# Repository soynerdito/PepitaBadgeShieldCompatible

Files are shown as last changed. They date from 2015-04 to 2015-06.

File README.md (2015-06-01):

# PepitaBadgeShieldCompatible
BSides Badge (codename Pepita). Arduino shield compatible.

To program board use an external USBAS at 5V. Connect 5V input voltage via the pin that says 3.3V to send 5V straight to the  atmega chip. If input voltage goes to the input pin it will go through the 3.3V regulator and in my first test it didn't allowed me to program the chip.

#Configure Arduino IDE 1.6.4
Step 1:
File->Preferences
 Paste in "Additional Boards Manager URLS:" https://github.com/soynerdito/PepitaBadgeShieldCompatible/raw/master/Arduino/IDE_Board_Manager/package_bsidespr_index.json
Click OK

Step 2:
Tools->Boards->Boards Manager
	Select BSides Badge from list and click Install

Step 3: Activate the board
Tools->Boads
	Select BSides Badge 2015 from the available boards
	
Step 4: Set the programmer
Tools->Programmer
	Select USBasp

# Flashing firmware
avrdude -c usbasp -b 19200 -p atmega328p -P /dev/ttyACM0 -U flash:w:mega32p_16mhz_program_on_reset.hex

#Fuses
avrdude -c usbasp -p atmega328p -b19200 -P /dev/ttyACM0 -U lfuse:w:0xf7:m -U hfuse:w:0xdA:m -U efuse:w:0x03:m

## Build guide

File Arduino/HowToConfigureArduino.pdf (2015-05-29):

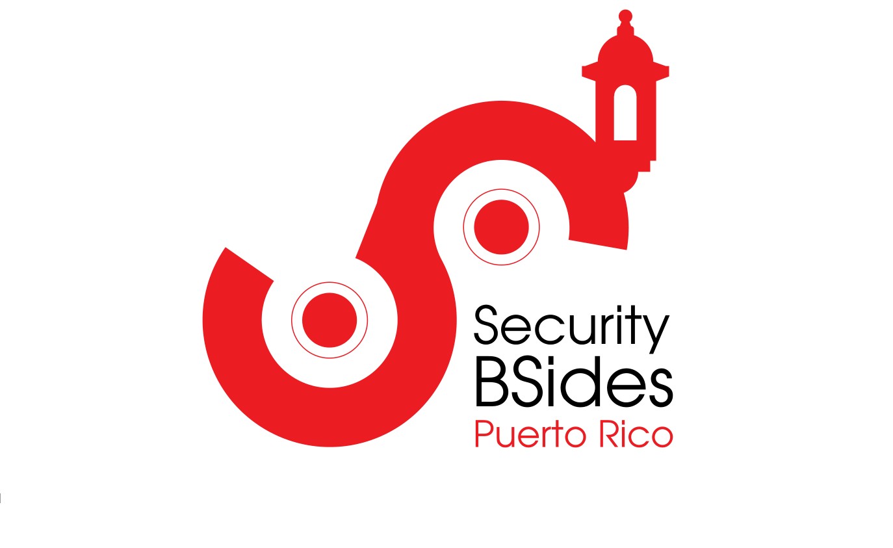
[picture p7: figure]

# How to Configure Arduino 1.6.4 for Bsides PR 2015 Badge

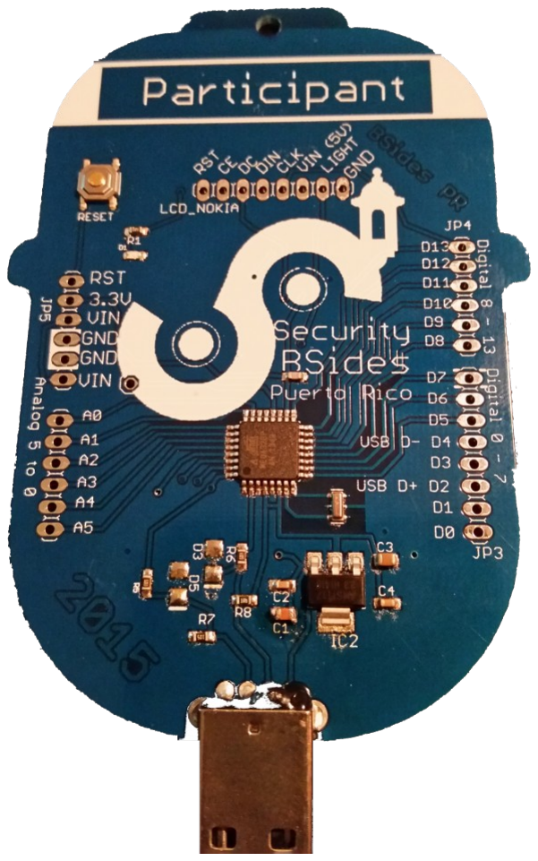
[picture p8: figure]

1

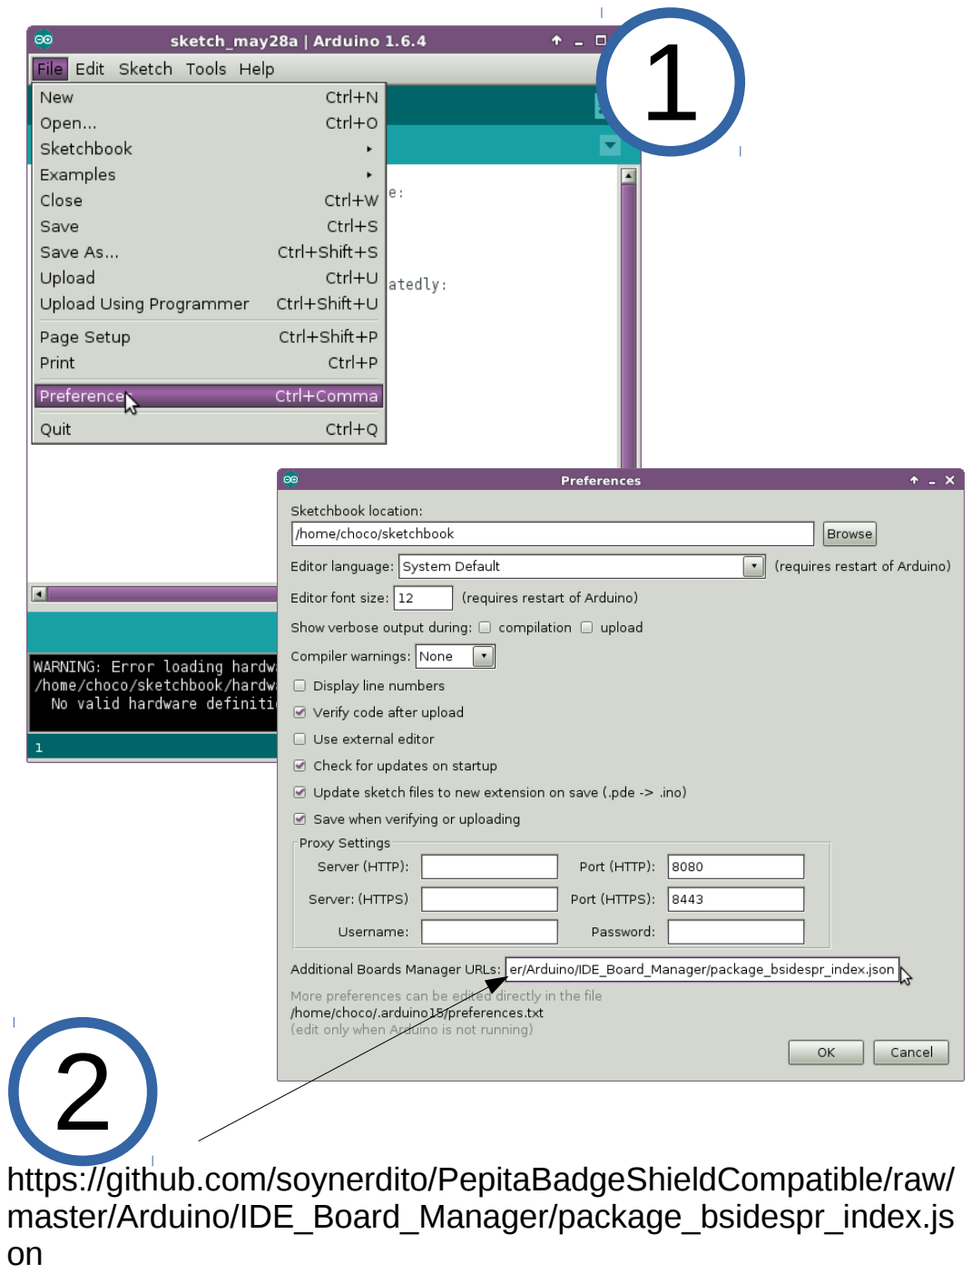
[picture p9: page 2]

https://github.com/soynerdito/PepitaBadgeShieldCompatible/raw/master/Arduino/IDE_Board_Manager/package_bsidespr_index.js on

2

3

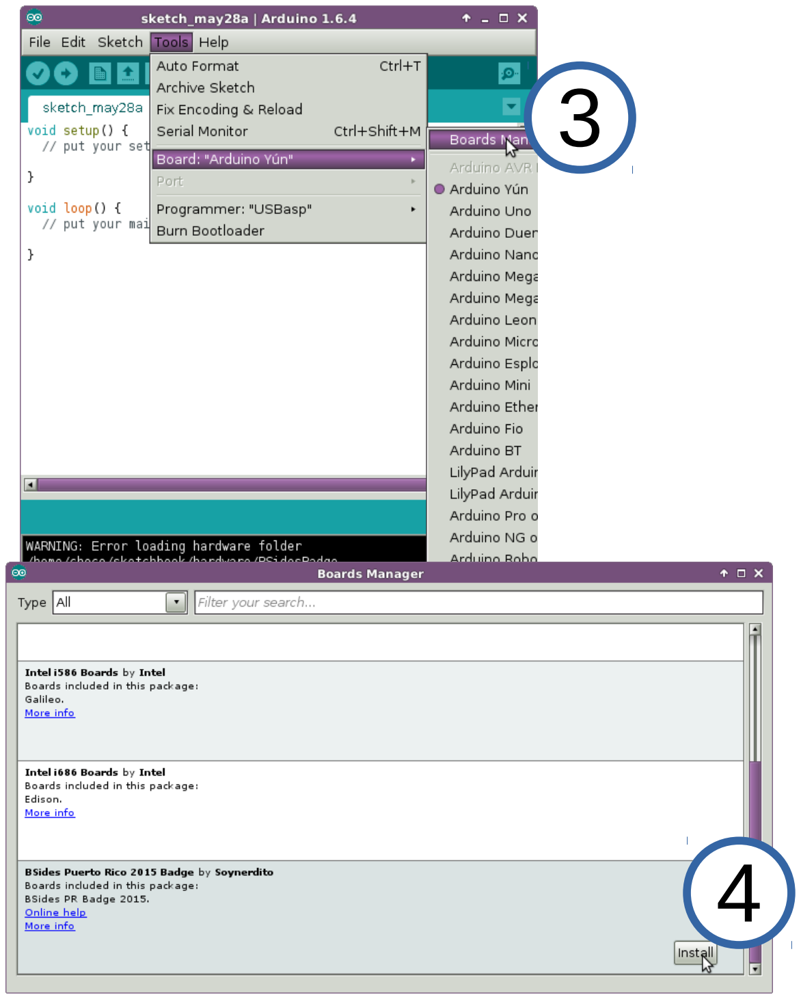
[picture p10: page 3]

4

5

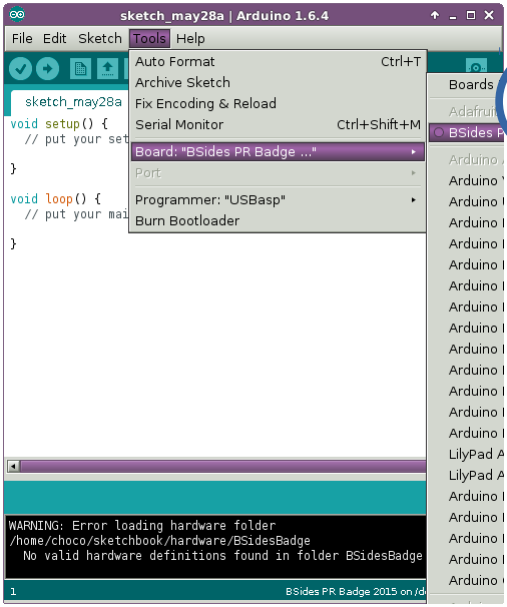
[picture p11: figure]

Your IDE is ready to compile and download projects to your badge.
Linux/MAC no drivers needed

Linux
create a file /etc/udev/rules.d/Usbasp.rules with this content SUBSYSTEMS=="usb", ATTRS{idVendor}=="16c0", ATTRS{idProduct}=="05dc", GROUP="users", MODE="0666"

Windows
Driver: http://www.fischl.de/usbasp/

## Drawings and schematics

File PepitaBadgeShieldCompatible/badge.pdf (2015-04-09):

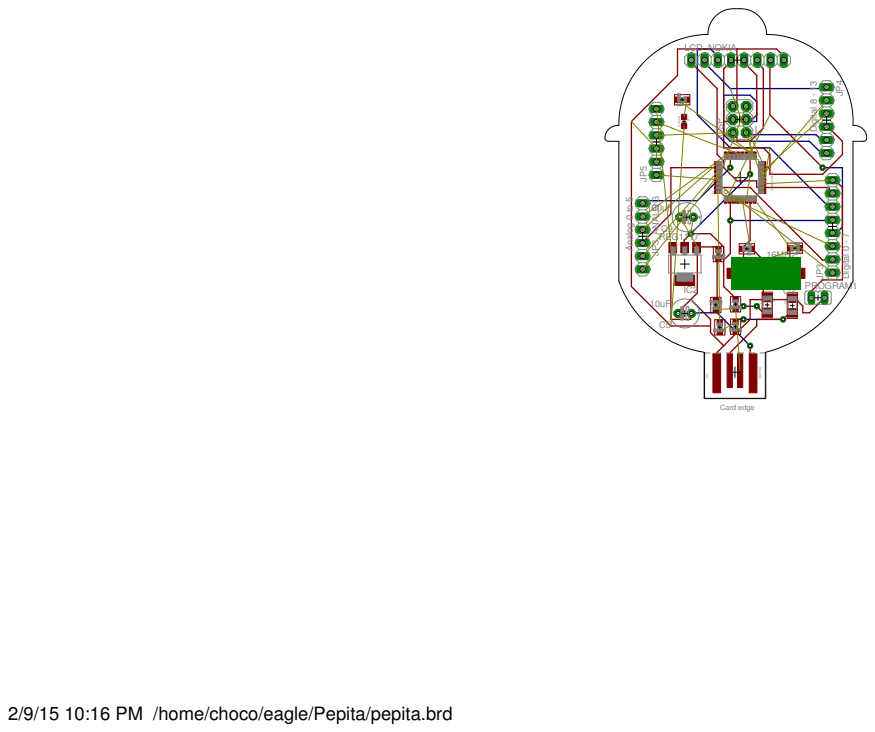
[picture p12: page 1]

2/9/15 10:16 PM /home/choco/eagle/Pepita/pepita.brd

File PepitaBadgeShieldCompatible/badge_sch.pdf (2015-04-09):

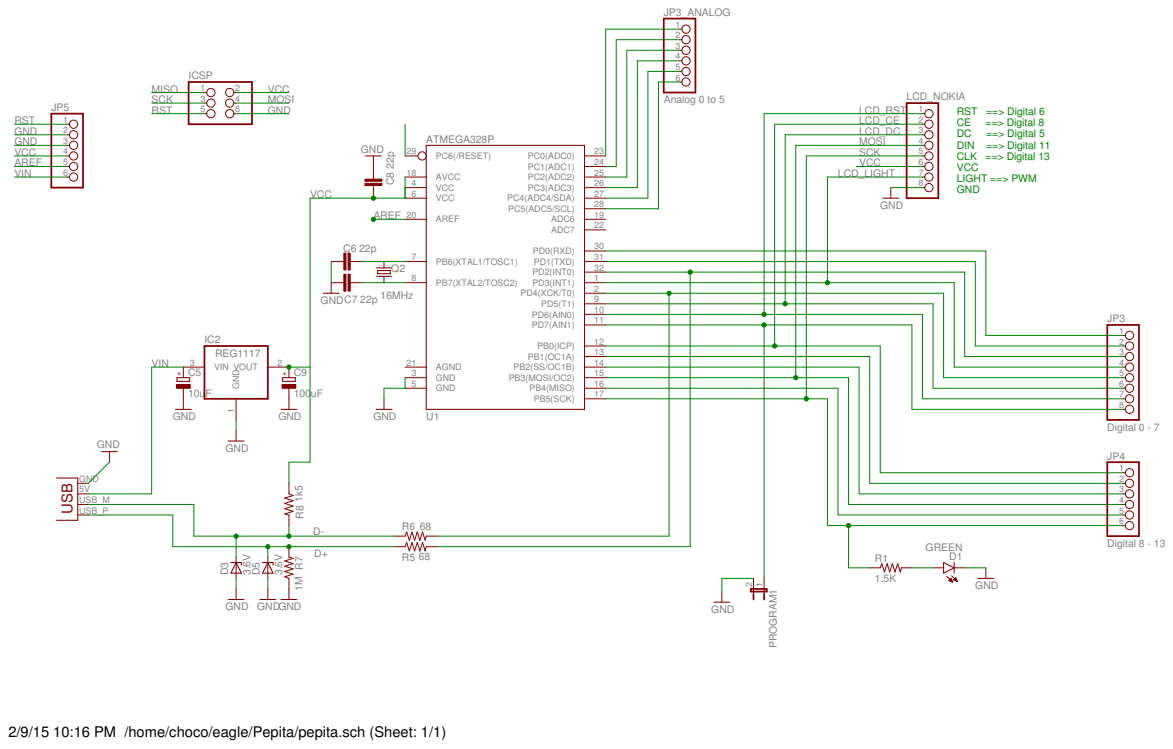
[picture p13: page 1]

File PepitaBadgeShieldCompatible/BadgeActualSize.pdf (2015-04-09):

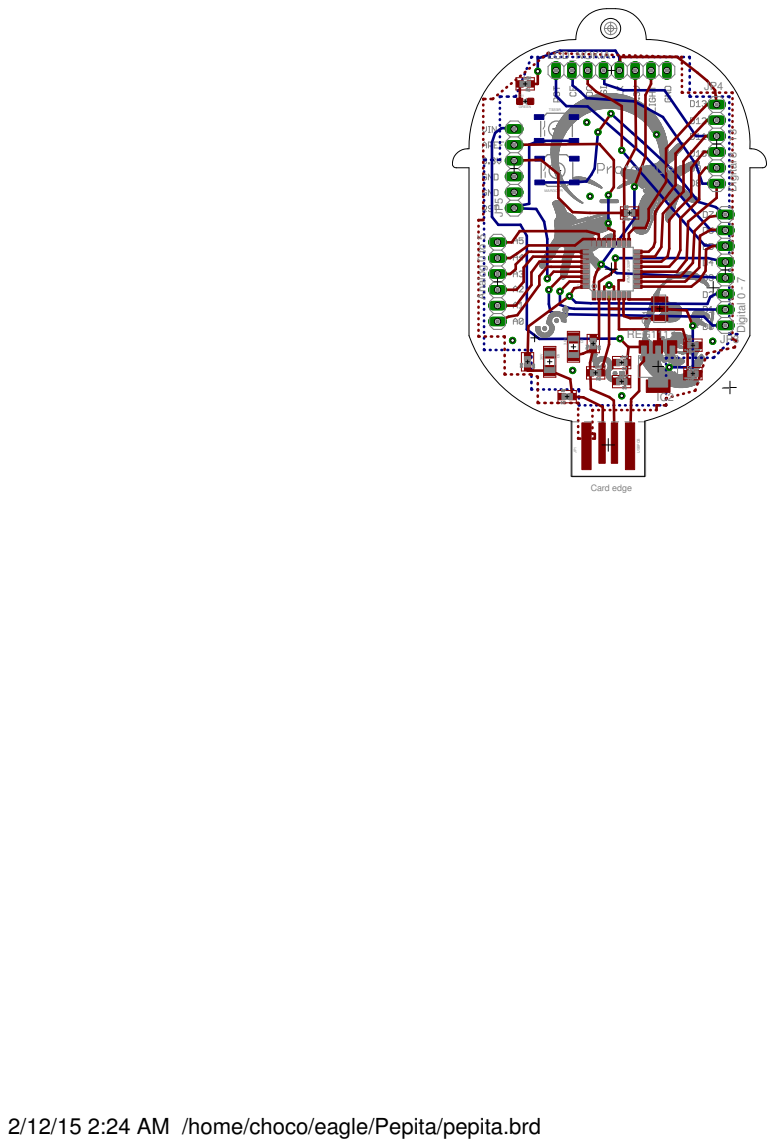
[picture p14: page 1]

2/12/15 2:24 AM /home/choco/eagle/Pepita/pepita.brd

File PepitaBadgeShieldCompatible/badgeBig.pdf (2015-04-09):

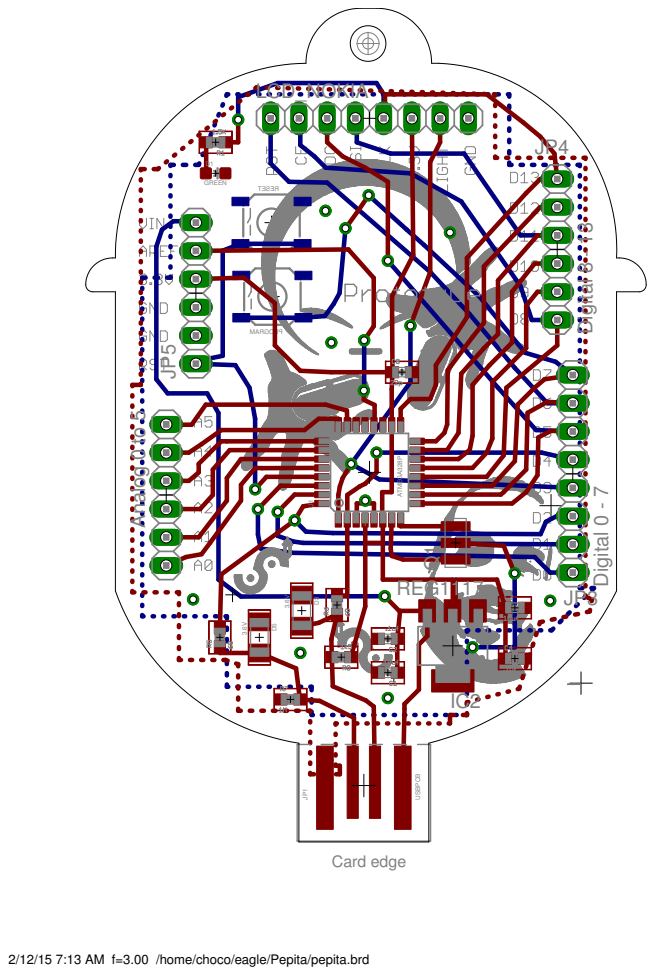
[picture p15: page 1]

2/12/15 7:13 AM f=3.00 /home/choco/eagle/Pepita/pepita.brd

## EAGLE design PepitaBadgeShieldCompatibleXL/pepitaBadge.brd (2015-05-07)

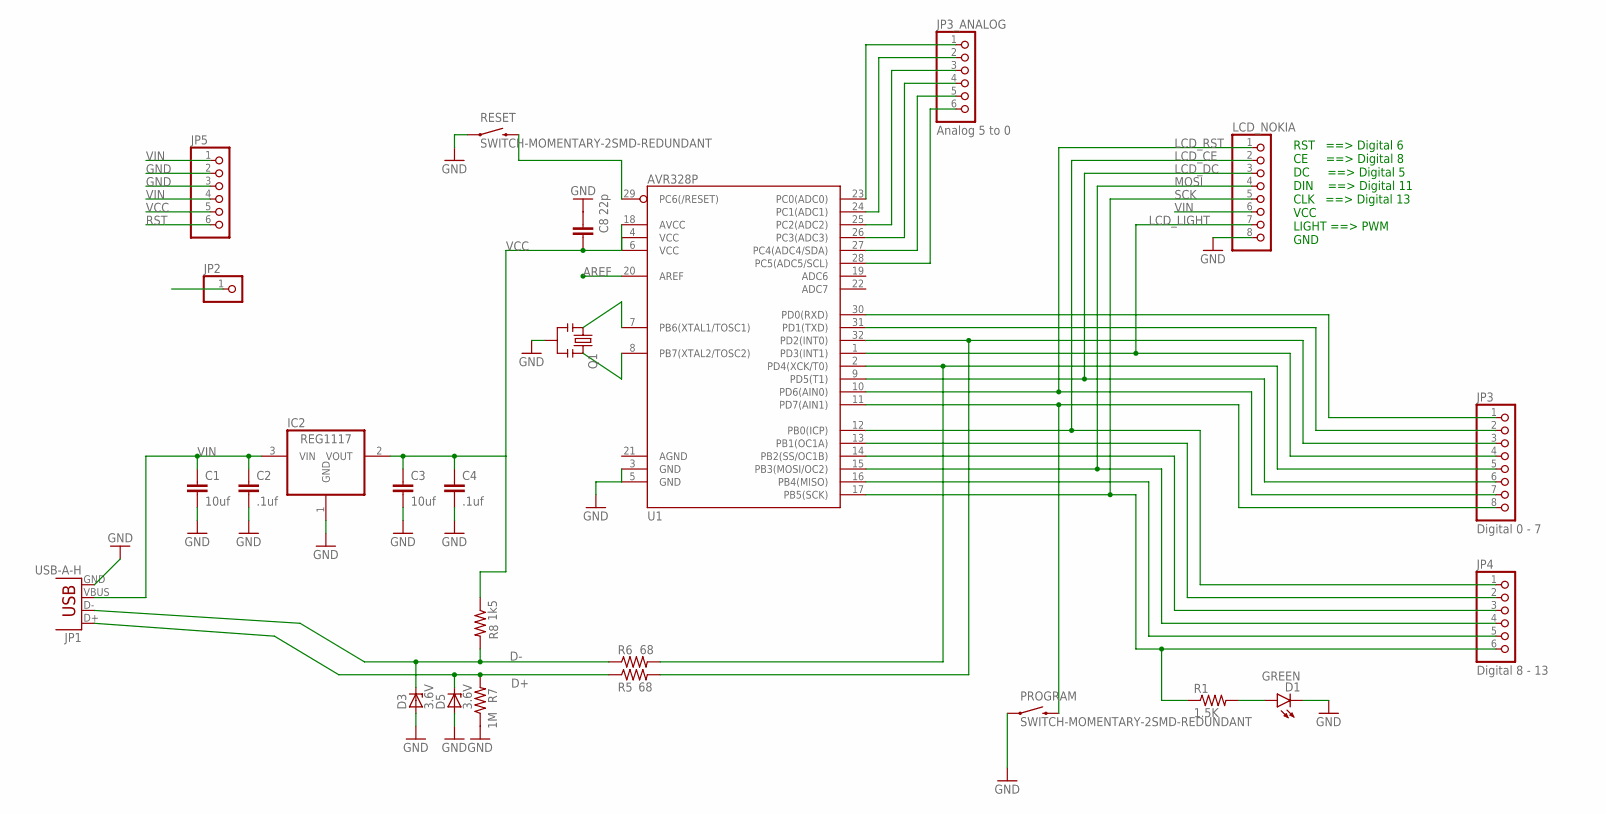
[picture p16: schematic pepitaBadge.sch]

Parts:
C1, C3: 10uf; 0805
C2, C4: .1uf; 0603-CAP
C8: 22p; 0603-CAP
D1: GREEN; LED-0603
D3, D5: 3.6V; 1206
IC2: REG1117; SOT223
JP1: USB-A-H
JP2: PINHD-1X1; 1X01
JP3: Digital 0 - 7; 1X08
JP3_ANALOG: Analog 5 to 0; 1X06
JP4: Digital 8 - 13; 1X06
JP5: PINHD-1X6; 1X06
LCD_NOKIA: PINHD-1X8; 1X08
PROGRAM: SWITCH-MOMENTARY-2SMD-REDUNDANT; TACTILE-SWITCH-SMD
Q1: RESONATOR16MHZ; RESONATOR-SMD
R1: 1.5K; 0603-RES
R5, R6: 68; 0603-RES
R7: 1M; 0603-RES
R8: 1k5; 0603-RES
RESET: SWITCH-MOMENTARY-2SMD-REDUNDANT; TACTILE-SWITCH-SMD
U1: AVR328P; TQFP32-08

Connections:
A5: JP3_ANALOG.6, U1.28 (PC5(ADC5/SCL))
AREF: JP2.1, U1.20 (AREF)
D+: D5.2 (C), JP1.D+, R5.1, R7.2
D-: D3.2 (C), JP1.D-, R6.1, R8.2
GND: C1.2, C2.2, C3.2, C4.2, C8.2, D1.C, D3.1 (A), D5.1 (A), IC2.1 (GND), JP1.GND, JP5.2, JP5.3, LCD_NOKIA.8, PROGRAM.1, PROGRAM.2 (1), Q1.2, R7.1, RESET.1, RESET.2 (1), U1.3 (GND), U1.5 (GND)
LCD_CE: JP4.1, LCD_NOKIA.2, U1.12 (PB0(ICP))
LCD_DC: JP3.6, LCD_NOKIA.3, U1.9 (PD5(T1))
LCD_LIGHT: JP3.4, LCD_NOKIA.7, U1.1 (PD3(INT1))
LCD_RST: JP3.7, LCD_NOKIA.1, U1.10 (PD6(AIN0))
MISO: JP4.5, U1.16 (PB4(MISO))
MOSI: JP4.4, LCD_NOKIA.4, U1.15 (PB3(MOSI/OC2))
unnamed: D1.A, R1.2
unnamed: JP3_ANALOG.5, U1.27 (PC4(ADC4/SDA))
unnamed: JP3_ANALOG.4, U1.26 (PC3(ADC3))
unnamed: JP3_ANALOG.3, U1.25 (PC2(ADC2))
unnamed: JP3.5, R6.2, U1.2 (PD4(XCK/T0))
unnamed: JP3_ANALOG.2, U1.24 (PC1(ADC1))
unnamed: Q1.1, U1.7 (PB6(XTAL1/TOSC1))
unnamed: JP3_ANALOG.1, U1.23 (PC0(ADC0))
unnamed: Q1.3, U1.8 (PB7(XTAL2/TOSC2))
unnamed: JP4.2, U1.13 (PB1(OC1A))
unnamed: JP4.3, U1.14 (PB2(SS/OC1B))
unnamed: JP3.3, R5.2, U1.32 (PD2(INT0))
PD7: JP3.8, PROGRAM.3 (2), PROGRAM.4 (2), U1.11 (PD7(AIN1))
RST: JP5.6, RESET.3 (2), RESET.4 (2), U1.29 (PC6(/RESET))
RXD: JP3.1, U1.30 (PD0(RXD))
SCK: JP4.6, LCD_NOKIA.5, R1.1, U1.17 (PB5(SCK))
TXD: JP3.2, U1.31 (PD1(TXD))
VCC: C3.1, C4.1, C8.1, IC2.2 (VOUT), JP5.5, R8.1, U1.4 (VCC), U1.6 (VCC), U1.18 (AVCC)
VIN: C1.1, C2.1, IC2.3 (VIN), JP1.VBUS, JP5.1, JP5.4, LCD_NOKIA.6

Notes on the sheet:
RST ==> Digital 6 CE ==> Digital 8 DC ==> Digital 5 DIN ==> Digital 11 CLK ==> Digital 13 VCC LIGHT ==> PWM GND

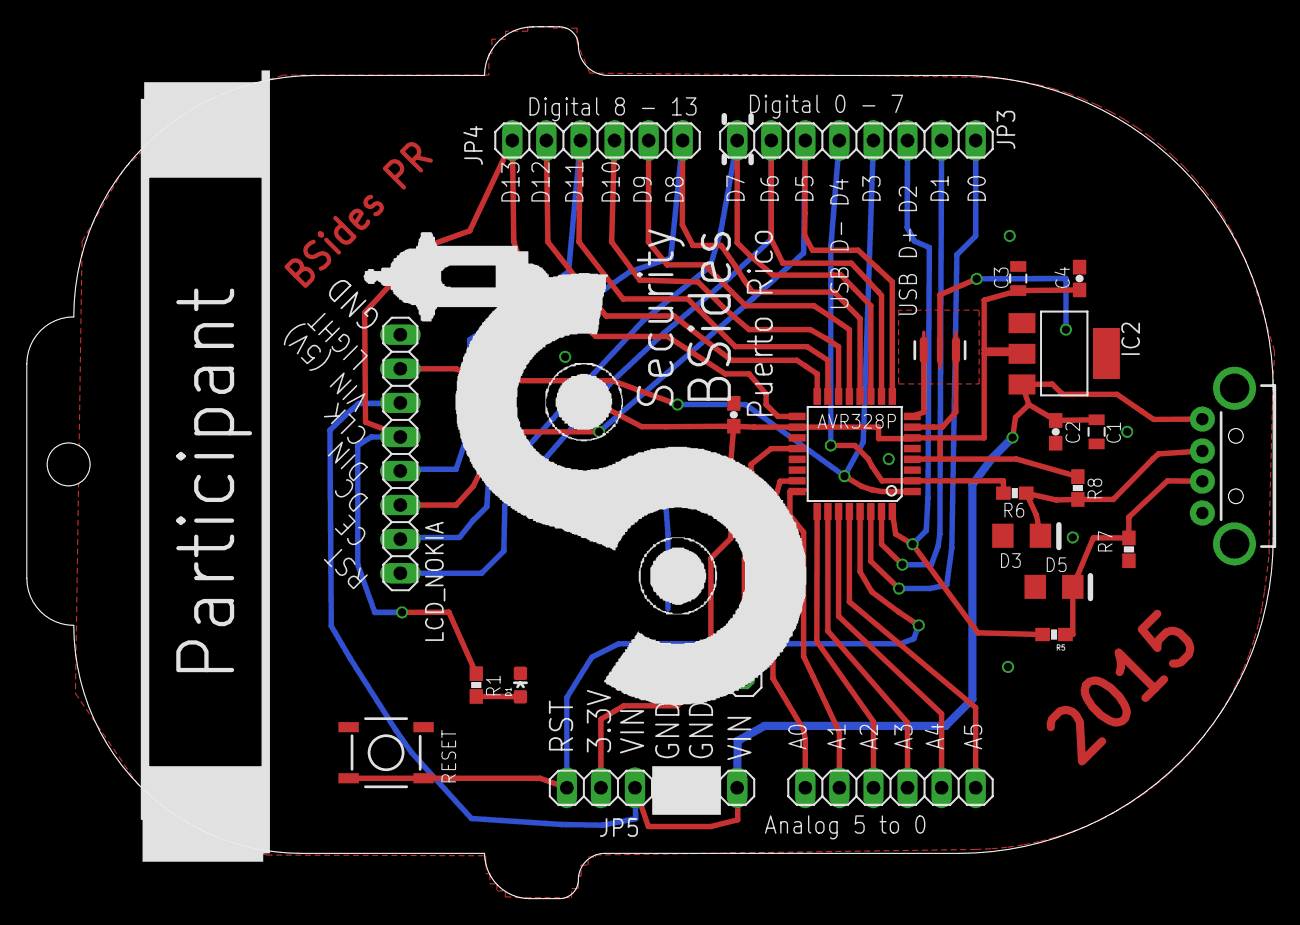
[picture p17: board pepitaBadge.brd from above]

Board: 2 copper layers, 92.9 x 65.0 mm, 27 parts (1 on the bottom side), 30 nets.

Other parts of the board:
U$2: OBSIDISLOGO_BOTTOM
U$5: BSIDES_LOGO_NTB_PIC_ONLY

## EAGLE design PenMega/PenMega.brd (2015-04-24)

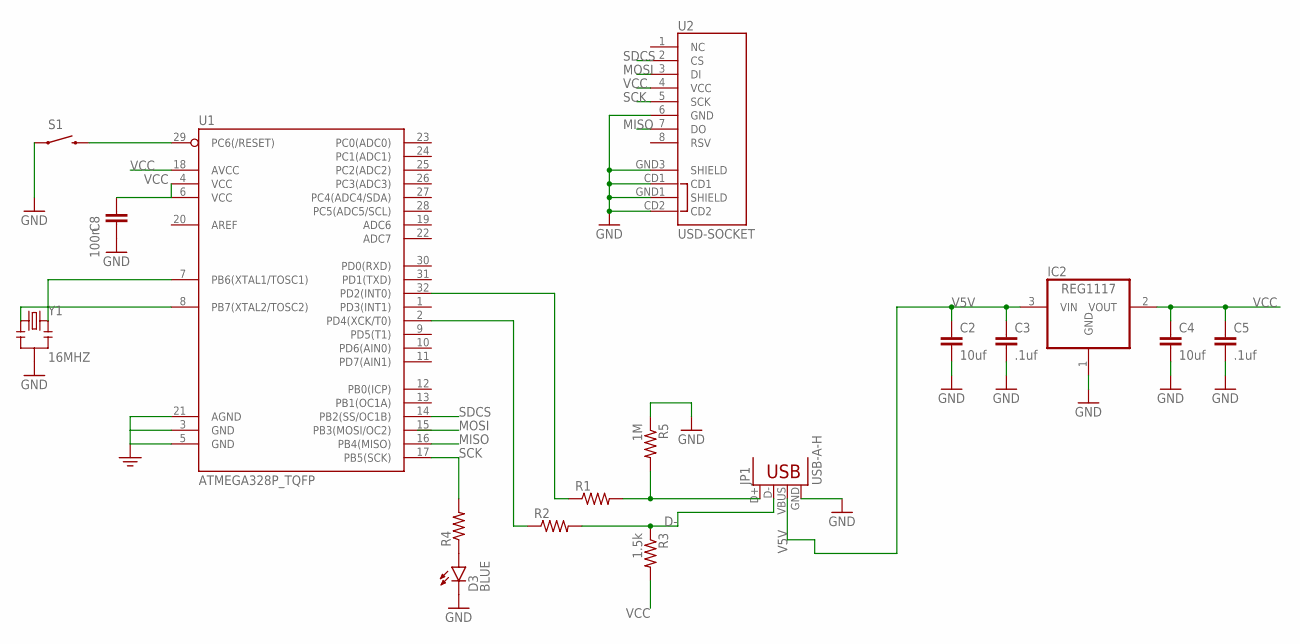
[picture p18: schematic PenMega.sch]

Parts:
C2, C4: 10uf; 0805
C3, C5: .1uf; 0603-CAP
C8: 100n; 0603-CAP
D3: BLUE; LED-0603
IC2: REG1117; SOT223
JP1: USB-A-H
R1, R2, R4: RESISTOR0603-RES; 0603-RES
R3: 1.5k; 0603-RES
R5: 1M; 0603-RES
S1: SWITCH-MOMENTARY-2SMD; TACTILE-SWITCH-SMD
U1: ATMEGA328P_TQFP; TQFP32-08
U2: USD-SOCKET; MICROSD_1:1
Y1: 16MHZ; RESONATOR-SMD

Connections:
D-: JP1.D-, R2.2, R3.1
GND: C2.2, C3.2, C4.2, C5.2, C8.2, D3.C, IC2.1 (GND), JP1.GND, R5.1, S1.1, U1.3 (GND), U1.5 (GND), U1.21 (AGND), U2.6 (GND), U2.CD1, U2.CD2, U2.GND1 (SHIELD), U2.GND3 (SHIELD), Y1.2
MISO: U1.16 (PB4(MISO)), U2.7 (DO)
MOSI: U2.3 (DI)
unnamed: U1.8 (PB7(XTAL2/TOSC2)), Y1.1
unnamed: U1.7 (PB6(XTAL1/TOSC1)), Y1.3
unnamed: JP1.D+, R1.2, R5.2
unnamed: R2.1, U1.2 (PD4(XCK/T0))
unnamed: R1.1, U1.32 (PD2(INT0))
unnamed: S1.3 (2), U1.29 (PC6(/RESET))
unnamed: D3.A, R4.1
SCK: R4.2, U1.17 (PB5(SCK)), U2.5 (SCK)
SDCS: U1.14 (PB2(SS/OC1B)), U2.2 (CS)
V5V: C2.1, C3.1, IC2.3 (VIN), JP1.VBUS
VCC: C4.1, C5.1, C8.1, IC2.2 (VOUT), R3.2, U1.4 (VCC), U1.6 (VCC), U1.18 (AVCC), U2.4 (VCC)

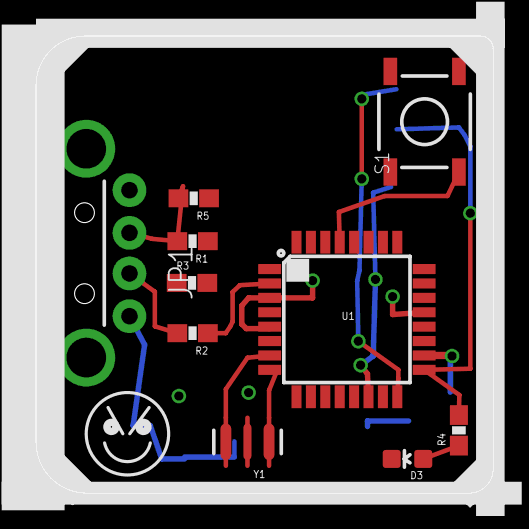
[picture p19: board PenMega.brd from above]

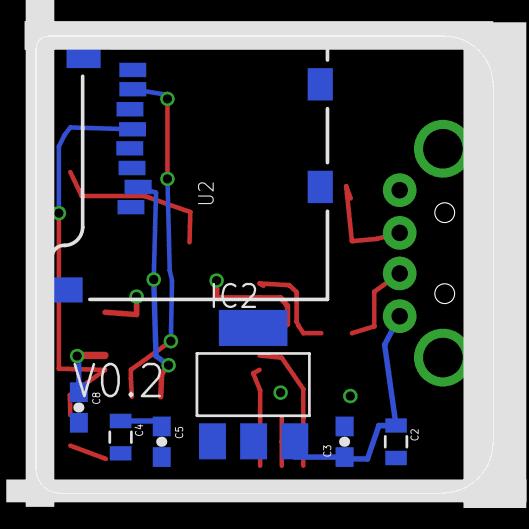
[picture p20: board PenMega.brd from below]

Board: 2 copper layers, 25.4 x 25.4 mm, 17 parts (7 on the bottom side), 14 nets.

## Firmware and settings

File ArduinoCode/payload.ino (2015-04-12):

#include "UsbKeyboard.h"

#define BUTTON_PIN 7

// If the timer isr is corrected
// to not take so long change this to 0.
#define BYPASS_TIMER_ISR 1

void doPayload();


void setup() {
  pinMode(BUTTON_PIN, INPUT);
  digitalWrite(BUTTON_PIN, HIGH);
  
#if BYPASS_TIMER_ISR
  // disable timer 0 overflow interrupt (used for millis)
  TIMSK0&=!(1<<TOIE0); // ++
#endif

}


#if BYPASS_TIMER_ISR
void delayMs(unsigned int ms) {
   /*
  */ 
  for (int i = 0; i < ms; i++) {
    delayMicroseconds(1000);
  }
}
#endif


void sendKeys( int keys[] )
{
  int i=0;
  while(keys[i] != 0 )
  {
    UsbKeyboard.sendKeyStroke( keys[i] );
    i++;
  }
}
int skipCount=0;
void loop() {
  
  UsbKeyboard.update();

  digitalWrite(13, !digitalRead(13));

  if( skipCount > 100 ){
    doPayload();
    skipCount = 0;
  }
  skipCount++;
     
  waitSome(120);
}

void waitSome( unsigned ms ){
  #if BYPASS_TIMER_ISR  // check if timer isr fixed.
      delayMs(ms);
  #else
      delay(ms);
  #endif
}
//Example Mod Keys
//UsbKeyboard.sendKeyStroke(KEY_R,    MOD_GUI_LEFT);
//UsbKeyboard.sendKeyStroke(KEY_F3,    MOD_ALT_LEFT);
/*
MOD_CONTROL_LEFT
MOD_SHIFT_LEFT
MOD_ALT_LEFT
MOD_GUI_LEFT
MOD_CONTROL_RIGHT
MOD_SHIFT_RIGHT
MOD_ALT_RIGHT
MOD_GUI_RIGHT
*/


void onWrite(unsigned char*, unsigned char )
{

}
void doPayload(){
	UsbKeyboard.sendKeyStroke( KEY_P );
	UsbKeyboard.sendKeyStroke( KEY_L );
	UsbKeyboard.sendKeyStroke( KEY_U );
	UsbKeyboard.sendKeyStroke( KEY_M );
	UsbKeyboard.sendKeyStroke( KEY_A );
	UsbKeyboard.sendKeyStroke( KEY_ENTER );
	UsbKeyboard.sendKeyStroke( KEY_ENTER );
	UsbKeyboard.sendKeyStroke( KEY_ENTER );
	UsbKeyboard.sendKeyStroke( KEY_E );
	UsbKeyboard.sendKeyStroke( KEY_S );
	UsbKeyboard.sendKeyStroke( KEY_T );
	UsbKeyboard.sendKeyStroke( KEY_E );
	UsbKeyboard.sendKeyStroke( KEY_SPACE );
	UsbKeyboard.sendKeyStroke( KEY_F );
	UsbKeyboard.sendKeyStroke( KEY_U );
	UsbKeyboard.sendKeyStroke( KEY_E );
	UsbKeyboard.sendKeyStroke( KEY_SPACE );
	UsbKeyboard.sendKeyStroke( KEY_M );
	UsbKeyboard.sendKeyStroke( KEY_I );
	UsbKeyboard.sendKeyStroke( KEY_SPACE );
	UsbKeyboard.sendKeyStroke( KEY_P );
	UsbKeyboard.sendKeyStroke( KEY_A );
	UsbKeyboard.sendKeyStroke( KEY_Y );
	UsbKeyboard.sendKeyStroke( KEY_L );
	UsbKeyboard.sendKeyStroke( KEY_O );
	UsbKeyboard.sendKeyStroke( KEY_A );
	UsbKeyboard.sendKeyStroke( KEY_D );
	UsbKeyboard.sendKeyStroke( KEY_ENTER );
	UsbKeyboard.sendKeyStroke( KEY_ENTER );
	UsbKeyboard.sendKeyStroke( KEY_O );
	UsbKeyboard.sendKeyStroke( KEY_SPACE );
	UsbKeyboard.sendKeyStroke( KEY_SPACE );
	UsbKeyboard.sendKeyStroke( KEY_SPACE );
	UsbKeyboard.sendKeyStroke( KEY_SPACE );
	UsbKeyboard.sendKeyStroke( KEY_SPACE );
	UsbKeyboard.sendKeyStroke( KEY_SPACE );
	UsbKeyboard.sendKeyStroke( KEY_SPACE );
	UsbKeyboard.sendKeyStroke( KEY_SPACE );
	UsbKeyboard.sendKeyStroke( KEY_SPACE );
	UsbKeyboard.sendKeyStroke( KEY_SPACE );
	UsbKeyboard.sendKeyStroke( KEY_TILDE );
	UsbKeyboard.sendKeyStroke( KEY_O );
	UsbKeyboard.sendKeyStroke( KEY_SPACE );
	UsbKeyboard.sendKeyStroke( KEY_SPACE );
	UsbKeyboard.sendKeyStroke( KEY_SPACE );
	UsbKeyboard.sendKeyStroke( KEY_SPACE );
	UsbKeyboard.sendKeyStroke( KEY_O );
	UsbKeyboard.sendKeyStroke( KEY_O );
	UsbKeyboard.sendKeyStroke( KEY_SPACE );
	UsbKeyboard.sendKeyStroke( KEY_SPACE );
	UsbKeyboard.sendKeyStroke( KEY_SPACE );
	UsbKeyboard.sendKeyStroke( KEY_SPACE );
	UsbKeyboard.sendKeyStroke( KEY_SPACE );
	UsbKeyboard.sendKeyStroke( KEY_PERIOD );
	UsbKeyboard.sendKeyStroke( KEY_O );
	UsbKeyboard.sendKeyStroke( KEY_O );
	UsbKeyboard.sendKeyStroke( KEY_O );
	UsbKeyboard.sendKeyStroke( KEY_O );
	UsbKeyboard.sendKeyStroke( KEY_O );
	UsbKeyboard.sendKeyStroke( KEY_PERIOD );
	UsbKeyboard.sendKeyStroke( KEY_SPACE );
	UsbKeyboard.sendKeyStroke( KEY_SPACE );
	UsbKeyboard.sendKeyStroke( KEY_SPACE );
	UsbKeyboard.sendKeyStroke( KEY_SPACE );
	UsbKeyboard.sendKeyStroke( KEY_SPACE );
	UsbKeyboard.sendKeyStroke( KEY_SPACE );
	UsbKeyboard.sendKeyStroke( KEY_SPACE );
	UsbKeyboard.sendKeyStroke( KEY_SPACE );
	UsbKeyboard.sendKeyStroke( KEY_SPACE );
	UsbKeyboard.sendKeyStroke( KEY_PERIOD );
	UsbKeyboard.sendKeyStroke( KEY_O );
	UsbKeyboard.sendKeyStroke( KEY_O );
	UsbKeyboard.sendKeyStroke( KEY_O );
	UsbKeyboard.sendKeyStroke( KEY_O );
	UsbKeyboard.sendKeyStroke( KEY_O );
	UsbKeyboard.sendKeyStroke( KEY_PERIOD );
	UsbKeyboard.sendKeyStroke( KEY_SPACE );
	UsbKeyboard.sendKeyStroke( KEY_SPACE );
	UsbKeyboard.sendKeyStroke( KEY_SPACE );
	UsbKeyboard.sendKeyStroke( KEY_O );
	UsbKeyboard.sendKeyStroke( KEY_SPACE );
	UsbKeyboard.sendKeyStroke( KEY_SPACE );
	UsbKeyboard.sendKeyStroke( KEY_SPACE );
	UsbKeyboard.sendKeyStroke( KEY_SPACE );
	UsbKeyboard.sendKeyStroke( KEY_SPACE );
	UsbKeyboard.sendKeyStroke( KEY_SPACE );
	UsbKeyboard.sendKeyStroke( KEY_SPACE );
	UsbKeyboard.sendKeyStroke( KEY_O );
	UsbKeyboard.sendKeyStroke( KEY_SPACE );
	UsbKeyboard.sendKeyStroke( KEY_O );
	UsbKeyboard.sendKeyStroke( KEY_PERIOD );
	UsbKeyboard.sendKeyStroke( KEY_O );
	UsbKeyboard.sendKeyStroke( KEY_O );
	UsbKeyboard.sendKeyStroke( KEY_O );
	UsbKeyboard.sendKeyStroke( KEY_O );
	UsbKeyboard.sendKeyStroke( KEY_O );
	UsbKeyboard.sendKeyStroke( KEY_O );
	UsbKeyboard.sendKeyStroke( KEY_SPACE );
	UsbKeyboard.sendKeyStroke( KEY_SPACE );
	UsbKeyboard.sendKeyStroke( KEY_SPACE );
	UsbKeyboard.sendKeyStroke( KEY_SPACE );
	UsbKeyboard.sendKeyStroke( KEY_SPACE );
	UsbKeyboard.sendKeyStroke( KEY_SPACE );
	UsbKeyboard.sendKeyStroke( KEY_SPACE );
	UsbKeyboard.sendKeyStroke( KEY_O );
	UsbKeyboard.sendKeyStroke( KEY_O );
	UsbKeyboard.sendKeyStroke( KEY_O );
	UsbKeyboard.sendKeyStroke( KEY_O );
	UsbKeyboard.sendKeyStroke( KEY_O );
	UsbKeyboard.sendKeyStroke( KEY_O );
	UsbKeyboard.sendKeyStroke( KEY_O );
	UsbKeyboard.sendKeyStroke( KEY_SPACE );
	UsbKeyboard.sendKeyStroke( KEY_SPACE );
	UsbKeyboard.sendKeyStroke( KEY_SPACE );
	UsbKeyboard.sendKeyStroke( KEY_SPACE );
	UsbKeyboard.sendKeyStroke( KEY_O );
	UsbKeyboard.sendKeyStroke( KEY_O );
	UsbKeyboard.sendKeyStroke( KEY_SPACE );
	UsbKeyboard.sendKeyStroke( KEY_SPACE );
	UsbKeyboard.sendKeyStroke( KEY_SPACE );
	UsbKeyboard.sendKeyStroke( KEY_SPACE );
	UsbKeyboard.sendKeyStroke( KEY_SPACE );
	UsbKeyboard.sendKeyStroke( KEY_PERIOD );
	UsbKeyboard.sendKeyStroke( KEY_O );
	UsbKeyboard.sendKeyStroke( KEY_O );
	UsbKeyboard.sendKeyStroke( KEY_O );
	UsbKeyboard.sendKeyStroke( KEY_O );
	UsbKeyboard.sendKeyStroke( KEY_O );
	UsbKeyboard.sendKeyStroke( KEY_PERIOD );
	UsbKeyboard.sendKeyStroke( KEY_SPACE );
	UsbKeyboard.sendKeyStroke( KEY_SPACE );
	UsbKeyboard.sendKeyStroke( KEY_O );
	UsbKeyboard.sendKeyStroke( KEY_O );
	UsbKeyboard.sendKeyStroke( KEY_O );
	UsbKeyboard.sendKeyStroke( KEY_O );
	UsbKeyboard.sendKeyStroke( KEY_O );
	UsbKeyboard.sendKeyStroke( KEY_O );
	UsbKeyboard.sendKeyStroke( KEY_O );
	UsbKeyboard.sendKeyStroke( KEY_SPACE );
	UsbKeyboard.sendKeyStroke( KEY_SPACE );
	UsbKeyboard.sendKeyStroke( KEY_O );
	UsbKeyboard.sendKeyStroke( KEY_ENTER );
	UsbKeyboard.sendKeyStroke( KEY_O );
	UsbKeyboard.sendKeyStroke( KEY_SPACE );
	UsbKeyboard.sendKeyStroke( KEY_SPACE );
	UsbKeyboard.sendKeyStroke( KEY_SPACE );
	UsbKeyboard.sendKeyStroke( KEY_SPACE );
	UsbKeyboard.sendKeyStroke( KEY_SPACE );
	UsbKeyboard.sendKeyStroke( KEY_SPACE );
	UsbKeyboard.sendKeyStroke( KEY_SPACE );
	UsbKeyboard.sendKeyStroke( KEY_SPACE );
	UsbKeyboard.sendKeyStroke( KEY_SPACE );
	UsbKeyboard.sendKeyStroke( KEY_SPACE );
	UsbKeyboard.sendKeyStroke( KEY_SPACE );
	UsbKeyboard.sendKeyStroke( KEY_O );
	UsbKeyboard.sendKeyStroke( KEY_SPACE );
	UsbKeyboard.sendKeyStroke( KEY_SPACE );
	UsbKeyboard.sendKeyStroke( KEY_SPACE );
	UsbKeyboard.sendKeyStroke( KEY_O );
	UsbKeyboard.sendKeyStroke( KEY_SPACE );
	UsbKeyboard.sendKeyStroke( KEY_SPACE );
	UsbKeyboard.sendKeyStroke( KEY_O );
	UsbKeyboard.sendKeyStroke( KEY_SPACE );
	UsbKeyboard.sendKeyStroke( KEY_SPACE );
	UsbKeyboard.sendKeyStroke( KEY_SPACE );
	UsbKeyboard.sendKeyStroke( KEY_PERIOD );
	UsbKeyboard.sendKeyStroke( KEY_O );
	UsbKeyboard.sendKeyStroke( KEY_SPACE );
	UsbKeyboard.sendKeyStroke( KEY_SPACE );
	UsbKeyboard.sendKeyStroke( KEY_SPACE );
	UsbKeyboard.sendKeyStroke( KEY_SPACE );
	UsbKeyboard.sendKeyStroke( KEY_SPACE );
	UsbKeyboard.sendKeyStroke( KEY_O );
	UsbKeyboard.sendKeyStroke( KEY_PERIOD );
	UsbKeyboard.sendKeyStroke( KEY_SPACE );
	UsbKeyboard.sendKeyStroke( KEY_SPACE );
	UsbKeyboard.sendKeyStroke( KEY_SPACE );
	UsbKeyboard.sendKeyStroke( KEY_SPACE );
	UsbKeyboard.sendKeyStroke( KEY_SPACE );
	UsbKeyboard.sendKeyStroke( KEY_SPACE );
	UsbKeyboard.sendKeyStroke( KEY_SPACE );
	UsbKeyboard.sendKeyStroke( KEY_PERIOD );
	UsbKeyboard.sendKeyStroke( KEY_O );
	UsbKeyboard.sendKeyStroke( KEY_SPACE );
	UsbKeyboard.sendKeyStroke( KEY_SPACE );
	UsbKeyboard.sendKeyStroke( KEY_SPACE );
	UsbKeyboard.sendKeyStroke( KEY_SPACE );
	UsbKeyboard.sendKeyStroke( KEY_SPACE );
	UsbKeyboard.sendKeyStroke( KEY_O );
	UsbKeyboard.sendKeyStroke( KEY_PERIOD );
	UsbKeyboard.sendKeyStroke( KEY_SPACE );
	UsbKeyboard.sendKeyStroke( KEY_SPACE );
	UsbKeyboard.sendKeyStroke( KEY_O );
	UsbKeyboard.sendKeyStroke( KEY_SPACE );
	UsbKeyboard.sendKeyStroke( KEY_SPACE );
	UsbKeyboard.sendKeyStroke( KEY_SPACE );
	UsbKeyboard.sendKeyStroke( KEY_SPACE );
	UsbKeyboard.sendKeyStroke( KEY_SPACE );
	UsbKeyboard.sendKeyStroke( KEY_SPACE );
	UsbKeyboard.sendKeyStroke( KEY_SPACE );
	UsbKeyboard.sendKeyStroke( KEY_O );
	UsbKeyboard.sendKeyStroke( KEY_SPACE );
	UsbKeyboard.sendKeyStroke( KEY_SPACE );
	UsbKeyboard.sendKeyStroke( KEY_O );
	UsbKeyboard.sendKeyStroke( KEY_SPACE );
	UsbKeyboard.sendKeyStroke( KEY_SPACE );
	UsbKeyboard.sendKeyStroke( KEY_SPACE );
	UsbKeyboard.sendKeyStroke( KEY_SPACE );
	UsbKeyboard.sendKeyStroke( KEY_SPACE );
	UsbKeyboard.sendKeyStroke( KEY_SPACE );
	UsbKeyboard.sendKeyStroke( KEY_SPACE );
	UsbKeyboard.sendKeyStroke( KEY_SPACE );
	UsbKeyboard.sendKeyStroke( KEY_SPACE );
	UsbKeyboard.sendKeyStroke( KEY_SPACE );
	UsbKeyboard.sendKeyStroke( KEY_SPACE );
	UsbKeyboard.sendKeyStroke( KEY_SPACE );
	UsbKeyboard.sendKeyStroke( KEY_SPACE );
	UsbKeyboard.sendKeyStroke( KEY_O );
	UsbKeyboard.sendKeyStroke( KEY_SPACE );
	UsbKeyboard.sendKeyStroke( KEY_SPACE );
	UsbKeyboard.sendKeyStroke( KEY_SPACE );
	UsbKeyboard.sendKeyStroke( KEY_SPACE );
	UsbKeyboard.sendKeyStroke( KEY_SPACE );
	UsbKeyboard.sendKeyStroke( KEY_SPACE );
	UsbKeyboard.sendKeyStroke( KEY_SPACE );
	UsbKeyboard.sendKeyStroke( KEY_SPACE );
	UsbKeyboard.sendKeyStroke( KEY_SPACE );
	UsbKeyboard.sendKeyStroke( KEY_O );
	UsbKeyboard.sendKeyStroke( KEY_SPACE );
	UsbKeyboard.sendKeyStroke( KEY_SPACE );
	UsbKeyboard.sendKeyStroke( KEY_O );
	UsbKeyboard.sendKeyStroke( KEY_SPACE );
	UsbKeyboard.sendKeyStroke( KEY_SPACE );
	UsbKeyboard.sendKeyStroke( KEY_SPACE );
	UsbKeyboard.sendKeyStroke( KEY_PERIOD );
	UsbKeyboard.sendKeyStroke( KEY_O );
	UsbKeyboard.sendKeyStroke( KEY_SPACE );
	UsbKeyboard.sendKeyStroke( KEY_SPACE );
	UsbKeyboard.sendKeyStroke( KEY_SPACE );
	UsbKeyboard.sendKeyStroke( KEY_SPACE );
	UsbKeyboard.sendKeyStroke( KEY_SPACE );
	UsbKeyboard.sendKeyStroke( KEY_O );
	UsbKeyboard.sendKeyStroke( KEY_SPACE );
	UsbKeyboard.sendKeyStroke( KEY_SPACE );
	UsbKeyboard.sendKeyStroke( KEY_SPACE );
	UsbKeyboard.sendKeyStroke( KEY_SPACE );
	UsbKeyboard.sendKeyStroke( KEY_SPACE );
	UsbKeyboard.sendKeyStroke( KEY_O );
	UsbKeyboard.sendKeyStroke( KEY_SPACE );
	UsbKeyboard.sendKeyStroke( KEY_SPACE );
	UsbKeyboard.sendKeyStroke( KEY_SPACE );
	UsbKeyboard.sendKeyStroke( KEY_SPACE );
	UsbKeyboard.sendKeyStroke( KEY_O );
	UsbKeyboard.sendKeyStroke( KEY_ENTER );
	UsbKeyboard.sendKeyStroke( KEY_O );
	UsbKeyboard.sendKeyStroke( KEY_SPACE );
	UsbKeyboard.sendKeyStroke( KEY_SPACE );
	UsbKeyboard.sendKeyStroke( KEY_SPACE );
	UsbKeyboard.sendKeyStroke( KEY_SPACE );
	UsbKeyboard.sendKeyStroke( KEY_SPACE );
	UsbKeyboard.sendKeyStroke( KEY_SPACE );
	UsbKeyboard.sendKeyStroke( KEY_SPACE );
	UsbKeyboard.sendKeyStroke( KEY_SPACE );
	UsbKeyboard.sendKeyStroke( KEY_SPACE );
	UsbKeyboard.sendKeyStroke( KEY_SPACE );
	UsbKeyboard.sendKeyStroke( KEY_SPACE );
	UsbKeyboard.sendKeyStroke( KEY_O );
	UsbKeyboard.sendKeyStroke( KEY_SPACE );
	UsbKeyboard.sendKeyStroke( KEY_SPACE );
	UsbKeyboard.sendKeyStroke( KEY_O );
	UsbKeyboard.sendKeyStroke( KEY_SPACE );
	UsbKeyboard.sendKeyStroke( KEY_SPACE );
	UsbKeyboard.sendKeyStroke( KEY_SPACE );
	UsbKeyboard.sendKeyStroke( KEY_SPACE );
	UsbKeyboard.sendKeyStroke( KEY_O );
	UsbKeyboard.sendKeyStroke( KEY_SPACE );
	UsbKeyboard.sendKeyStroke( KEY_SPACE );
	UsbKeyboard.sendKeyStroke( KEY_O );
	UsbKeyboard.sendKeyStroke( KEY_SPACE );
	UsbKeyboard.sendKeyStroke( KEY_SPACE );
	UsbKeyboard.sendKeyStroke( KEY_SPACE );
	UsbKeyboard.sendKeyStroke( KEY_SPACE );
	UsbKeyboard.sendKeyStroke( KEY_SPACE );
	UsbKeyboard.sendKeyStroke( KEY_SPACE );
	UsbKeyboard.sendKeyStroke( KEY_SPACE );
	UsbKeyboard.sendKeyStroke( KEY_O );
	UsbKeyboard.sendKeyStroke( KEY_SPACE );
	UsbKeyboard.sendKeyStroke( KEY_SPACE );
	UsbKeyboard.sendKeyStroke( KEY_SPACE );
	UsbKeyboard.sendKeyStroke( KEY_SPACE );
	UsbKeyboard.sendKeyStroke( KEY_SPACE );
	UsbKeyboard.sendKeyStroke( KEY_SPACE );
	UsbKeyboard.sendKeyStroke( KEY_SPACE );
	UsbKeyboard.sendKeyStroke( KEY_O );
	UsbKeyboard.sendKeyStroke( KEY_SPACE );
	UsbKeyboard.sendKeyStroke( KEY_SPACE );
	UsbKeyboard.sendKeyStroke( KEY_SPACE );
	UsbKeyboard.sendKeyStroke( KEY_SPACE );
	UsbKeyboard.sendKeyStroke( KEY_SPACE );
	UsbKeyboard.sendKeyStroke( KEY_SPACE );
	UsbKeyboard.sendKeyStroke( KEY_SPACE );
	UsbKeyboard.sendKeyStroke( KEY_O );
	UsbKeyboard.sendKeyStroke( KEY_SPACE );
	UsbKeyboard.sendKeyStroke( KEY_SPACE );
	UsbKeyboard.sendKeyStroke( KEY_O );
	UsbKeyboard.sendKeyStroke( KEY_SPACE );
	UsbKeyboard.sendKeyStroke( KEY_SPACE );
	UsbKeyboard.sendKeyStroke( KEY_SPACE );
	UsbKeyboard.sendKeyStroke( KEY_SPACE );
	UsbKeyboard.sendKeyStroke( KEY_SPACE );
	UsbKeyboard.sendKeyStroke( KEY_SPACE );
	UsbKeyboard.sendKeyStroke( KEY_SPACE );
	UsbKeyboard.sendKeyStroke( KEY_O );
	UsbKeyboard.sendKeyStroke( KEY_SPACE );
	UsbKeyboard.sendKeyStroke( KEY_SPACE );
	UsbKeyboard.sendKeyStroke( KEY_O );
	UsbKeyboard.sendKeyStroke( KEY_SPACE );
	UsbKeyboard.sendKeyStroke( KEY_SPACE );
	UsbKeyboard.sendKeyStroke( KEY_SPACE );
	UsbKeyboard.sendKeyStroke( KEY_SPACE );
	UsbKeyboard.sendKeyStroke( KEY_SPACE );
	UsbKeyboard.sendKeyStroke( KEY_SPACE );
	UsbKeyboard.sendKeyStroke( KEY_SPACE );
	UsbKeyboard.sendKeyStroke( KEY_SPACE );
	UsbKeyboard.sendKeyStroke( KEY_SPACE );
	UsbKeyboard.sendKeyStroke( KEY_SPACE );
	UsbKeyboard.sendKeyStroke( KEY_SPACE );
	UsbKeyboard.sendKeyStroke( KEY_SPACE );
	UsbKeyboard.sendKeyStroke( KEY_SPACE );
	UsbKeyboard.sendKeyStroke( KEY_O );
	UsbKeyboard.sendKeyStroke( KEY_SPACE );
	UsbKeyboard.sendKeyStroke( KEY_SPACE );
	UsbKeyboard.sendKeyStroke( KEY_SPACE );
	UsbKeyboard.sendKeyStroke( KEY_SPACE );
	UsbKeyboard.sendKeyStroke( KEY_SPACE );
	UsbKeyboard.sendKeyStroke( KEY_SPACE );
	UsbKeyboard.sendKeyStroke( KEY_SPACE );
	UsbKeyboard.sendKeyStroke( KEY_SPACE );
	UsbKeyboard.sendKeyStroke( KEY_O );
	UsbKeyboard.sendKeyStroke( KEY_SPACE );
	UsbKeyboard.sendKeyStroke( KEY_SPACE );
	UsbKeyboard.sendKeyStroke( KEY_SPACE );
	UsbKeyboard.sendKeyStroke( KEY_SPACE );
	UsbKeyboard.sendKeyStroke( KEY_O );
	UsbKeyboard.sendKeyStroke( KEY_SPACE );
	UsbKeyboard.sendKeyStroke( KEY_SPACE );
	UsbKeyboard.sendKeyStroke( KEY_O );
	UsbKeyboard.sendKeyStroke( KEY_SPACE );
	UsbKeyboard.sendKeyStroke( KEY_SPACE );
	UsbKeyboard.sendKeyStroke( KEY_SPACE );
	UsbKeyboard.sendKeyStroke( KEY_SPACE );
	UsbKeyboard.sendKeyStroke( KEY_SPACE );
	UsbKeyboard.sendKeyStroke( KEY_SPACE );
	UsbKeyboard.sendKeyStroke( KEY_SPACE );
	UsbKeyboard.sendKeyStroke( KEY_SPACE );
	UsbKeyboard.sendKeyStroke( KEY_SPACE );
	UsbKeyboard.sendKeyStroke( KEY_SPACE );
	UsbKeyboard.sendKeyStroke( KEY_SPACE );
	UsbKeyboard.sendKeyStroke( KEY_SPACE );
	UsbKeyboard.sendKeyStroke( KEY_O );
	UsbKeyboard.sendKeyStroke( KEY_SPACE );
	UsbKeyboard.sendKeyStroke( KEY_SPACE );
	UsbKeyboard.sendKeyStroke( KEY_SPACE );
	UsbKeyboard.sendKeyStroke( KEY_SPACE );
	UsbKeyboard.sendKeyStroke( KEY_O );
	UsbKeyboard.sendKeyStroke( KEY_ENTER );
	UsbKeyboard.sendKeyStroke( KEY_O );
	UsbKeyboard.sendKeyStroke( KEY_SPACE );
	UsbKeyboard.sendKeyStroke( KEY_SPACE );
	UsbKeyboard.sendKeyStroke( KEY_SPACE );
	UsbKeyboard.sendKeyStroke( KEY_SPACE );
	UsbKeyboard.sendKeyStroke( KEY_SPACE );
	UsbKeyboard.sendKeyStroke( KEY_SPACE );
	UsbKeyboard.sendKeyStroke( KEY_SPACE );
	UsbKeyboard.sendKeyStroke( KEY_SPACE );
	UsbKeyboard.sendKeyStroke( KEY_SPACE );
	UsbKeyboard.sendKeyStroke( KEY_SPACE );
	UsbKeyboard.sendKeyStroke( KEY_SPACE );
	UsbKeyboard.sendKeyStroke( KEY_O );
	UsbKeyboard.sendKeyStroke( KEY_SPACE );
	UsbKeyboard.sendKeyStroke( KEY_O );
	UsbKeyboard.sendKeyStroke( KEY_O );
	UsbKeyboard.sendKeyStroke( KEY_O );
	UsbKeyboard.sendKeyStroke( KEY_O );
	UsbKeyboard.sendKeyStroke( KEY_O );
	UsbKeyboard.sendKeyStroke( KEY_O );
	UsbKeyboard.sendKeyStroke( KEY_O );
	UsbKeyboard.sendKeyStroke( KEY_O );
	UsbKeyboard.sendKeyStroke( KEY_SPACE );
	UsbKeyboard.sendKeyStroke( KEY_O );
	UsbKeyboard.sendKeyStroke( KEY_SPACE );
	UsbKeyboard.sendKeyStroke( KEY_SPACE );
	UsbKeyboard.sendKeyStroke( KEY_SPACE );
	UsbKeyboard.sendKeyStroke( KEY_SPACE );
	UsbKeyboard.sendKeyStroke( KEY_SPACE );
	UsbKeyboard.sendKeyStroke( KEY_SPACE );
	UsbKeyboard.sendKeyStroke( KEY_SPACE );
	UsbKeyboard.sendKeyStroke( KEY_O );
	UsbKeyboard.sendKeyStroke( KEY_SPACE );
	UsbKeyboard.sendKeyStroke( KEY_SPACE );
	UsbKeyboard.sendKeyStroke( KEY_SPACE );
	UsbKeyboard.sendKeyStroke( KEY_SPACE );
	UsbKeyboard.sendKeyStroke( KEY_SPACE );
	UsbKeyboard.sendKeyStroke( KEY_SPACE );
	UsbKeyboard.sendKeyStroke( KEY_SPACE );
	UsbKeyboard.sendKeyStroke( KEY_O );
	UsbKeyboard.sendKeyStroke( KEY_SPACE );
	UsbKeyboard.sendKeyStroke( KEY_SPACE );
	UsbKeyboard.sendKeyStroke( KEY_SPACE );
	UsbKeyboard.sendKeyStroke( KEY_SPACE );
	UsbKeyboard.sendKeyStroke( KEY_SPACE );
	UsbKeyboard.sendKeyStroke( KEY_SPACE );
	UsbKeyboard.sendKeyStroke( KEY_SPACE );
	UsbKeyboard.sendKeyStroke( KEY_O );
	UsbKeyboard.sendKeyStroke( KEY_SPACE );
	UsbKeyboard.sendKeyStroke( KEY_SPACE );
	UsbKeyboard.sendKeyStroke( KEY_O );
	UsbKeyboard.sendKeyStroke( KEY_SPACE );
	UsbKeyboard.sendKeyStroke( KEY_SPACE );
	UsbKeyboard.sendKeyStroke( KEY_SPACE );
	UsbKeyboard.sendKeyStroke( KEY_SPACE );
	UsbKeyboard.sendKeyStroke( KEY_SPACE );
	UsbKeyboard.sendKeyStroke( KEY_SPACE );
	UsbKeyboard.sendKeyStroke( KEY_SPACE );
	UsbKeyboard.sendKeyStroke( KEY_O );
	UsbKeyboard.sendKeyStroke( KEY_SPACE );
	UsbKeyboard.sendKeyStroke( KEY_SPACE );
	UsbKeyboard.sendKeyStroke( KEY_O );
	UsbKeyboard.sendKeyStroke( KEY_O );
	UsbKeyboard.sendKeyStroke( KEY_O );
	UsbKeyboard.sendKeyStroke( KEY_O );
	UsbKeyboard.sendKeyStroke( KEY_SPACE );
	UsbKeyboard.sendKeyStroke( KEY_SPACE );
	UsbKeyboard.sendKeyStroke( KEY_SPACE );
	UsbKeyboard.sendKeyStroke( KEY_SPACE );
	UsbKeyboard.sendKeyStroke( KEY_SPACE );
	UsbKeyboard.sendKeyStroke( KEY_SPACE );
	UsbKeyboard.sendKeyStroke( KEY_SPACE );
	UsbKeyboard.sendKeyStroke( KEY_SPACE );
	UsbKeyboard.sendKeyStroke( KEY_SPACE );
	UsbKeyboard.sendKeyStroke( KEY_SPACE );
	UsbKeyboard.sendKeyStroke( KEY_O );
	UsbKeyboard.sendKeyStroke( KEY_O );
	UsbKeyboard.sendKeyStroke( KEY_O );
	UsbKeyboard.sendKeyStroke( KEY_O );
	UsbKeyboard.sendKeyStroke( KEY_O );
	UsbKeyboard.sendKeyStroke( KEY_SPACE );
	UsbKeyboard.sendKeyStroke( KEY_SPACE );
	UsbKeyboard.sendKeyStroke( KEY_SPACE );
	UsbKeyboard.sendKeyStroke( KEY_O );
	UsbKeyboard.sendKeyStroke( KEY_O );
	UsbKeyboard.sendKeyStroke( KEY_O );
	UsbKeyboard.sendKeyStroke( KEY_O );
	UsbKeyboard.sendKeyStroke( KEY_O );
	UsbKeyboard.sendKeyStroke( KEY_O );
	UsbKeyboard.sendKeyStroke( KEY_O );
	UsbKeyboard.sendKeyStroke( KEY_O );
	UsbKeyboard.sendKeyStroke( KEY_SPACE );
	UsbKeyboard.sendKeyStroke( KEY_O );
	UsbKeyboard.sendKeyStroke( KEY_SPACE );
	UsbKeyboard.sendKeyStroke( KEY_SPACE );
	UsbKeyboard.sendKeyStroke( KEY_SPACE );
	UsbKeyboard.sendKeyStroke( KEY_SPACE );
	UsbKeyboard.sendKeyStroke( KEY_SPACE );
	UsbKeyboard.sendKeyStroke( KEY_SPACE );
	UsbKeyboard.sendKeyStroke( KEY_SPACE );
	UsbKeyboard.sendKeyStroke( KEY_SPACE );
	UsbKeyboard.sendKeyStroke( KEY_SPACE );
	UsbKeyboard.sendKeyStroke( KEY_SPACE );
	UsbKeyboard.sendKeyStroke( KEY_SPACE );
	UsbKeyboard.sendKeyStroke( KEY_SPACE );
	UsbKeyboard.sendKeyStroke( KEY_O );
	UsbKeyboard.sendKeyStroke( KEY_SPACE );
	UsbKeyboard.sendKeyStroke( KEY_SPACE );
	UsbKeyboard.sendKeyStroke( KEY_SPACE );
	UsbKeyboard.sendKeyStroke( KEY_SPACE );
	UsbKeyboard.sendKeyStroke( KEY_O );
	UsbKeyboard.sendKeyStroke( KEY_ENTER );
	UsbKeyboard.sendKeyStroke( KEY_O );
	UsbKeyboard.sendKeyStroke( KEY_SPACE );
	UsbKeyboard.sendKeyStroke( KEY_SPACE );
	UsbKeyboard.sendKeyStroke( KEY_SPACE );
	UsbKeyboard.sendKeyStroke( KEY_SPACE );
	UsbKeyboard.sendKeyStroke( KEY_SPACE );
	UsbKeyboard.sendKeyStroke( KEY_O );
	UsbKeyboard.sendKeyStroke( KEY_SPACE );
	UsbKeyboard.sendKeyStroke( KEY_SPACE );
	UsbKeyboard.sendKeyStroke( KEY_SPACE );
	UsbKeyboard.sendKeyStroke( KEY_SPACE );
	UsbKeyboard.sendKeyStroke( KEY_SPACE );
	UsbKeyboard.sendKeyStroke( KEY_O );
	UsbKeyboard.sendKeyStroke( KEY_SPACE );
	UsbKeyboard.sendKeyStroke( KEY_O );
	UsbKeyboard.sendKeyStroke( KEY_SPACE );
	UsbKeyboard.sendKeyStroke( KEY_SPACE );
	UsbKeyboard.sendKeyStroke( KEY_SPACE );
	UsbKeyboard.sendKeyStroke( KEY_SPACE );
	UsbKeyboard.sendKeyStroke( KEY_SPACE );
	UsbKeyboard.sendKeyStroke( KEY_SPACE );
	UsbKeyboard.sendKeyStroke( KEY_O );
	UsbKeyboard.sendKeyStroke( KEY_SPACE );
	UsbKeyboard.sendKeyStroke( KEY_O );
	UsbKeyboard.sendKeyStroke( KEY_SPACE );
	UsbKeyboard.sendKeyStroke( KEY_SPACE );
	UsbKeyboard.sendKeyStroke( KEY_SPACE );
	UsbKeyboard.sendKeyStroke( KEY_SPACE );
	UsbKeyboard.sendKeyStroke( KEY_SPACE );
	UsbKeyboard.sendKeyStroke( KEY_SPACE );
	UsbKeyboard.sendKeyStroke( KEY_SPACE );
	UsbKeyboard.sendKeyStroke( KEY_O );
	UsbKeyboard.sendKeyStroke( KEY_SPACE );
	UsbKeyboard.sendKeyStroke( KEY_SPACE );
	UsbKeyboard.sendKeyStroke( KEY_SPACE );
	UsbKeyboard.sendKeyStroke( KEY_SPACE );
	UsbKeyboard.sendKeyStroke( KEY_SPACE );
	UsbKeyboard.sendKeyStroke( KEY_SPACE );
	UsbKeyboard.sendKeyStroke( KEY_SPACE );
	UsbKeyboard.sendKeyStroke( KEY_O );
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

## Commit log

2015-04-09 Adding Eagle Files
    [PenMega.brd, PenMega.sch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]
2015-04-11 Small fixes to XL design
    [pepitaBadge.brd]
2015-04-11 Adding instruction on how to flash using Arduino as an ISP
2015-04-12 Smooth PCB border and adding some Arduino code
    [pepitaBadge.brd]
2015-04-20 Trying to make this work, as of now first sent to manufacturing did not work with 6mills paths. changed to 10 mills.
    [PenMega.brd, PenMega.sch, pepitaBadge.brd]
2015-04-21 Partial fix for penmega. Removed un needed zener diodes
    [PenMega.brd, PenMega.sch]
2015-04-24 Partially working on fixing PenMega. Work in progress
    [PenMega.brd, PenMega.sch]
2015-05-02 Actual Gebers to be ordered for Staff and Speakers
    [pepitaBadge.GBL, pepitaBadge.GBO, pepitaBadge.GBP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]
2015-05-06 Participant gerbers
    [pepitaBadge.GBL, pepitaBadge.GBO, pepitaBadge.GBP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]
2015-05-07 Participant gerbers fix
    [pepitaBadge.brd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]
2015-05-28 Adding files to import on Arduino 1.6.4
2015-05-28 fix boards.txt
2015-05-28 How to Configure Arduino 1.6.4
2015-05-29 How to configure Badge on Arduino IDE
2016-12-04 Try for upgrade of arduino compatibility

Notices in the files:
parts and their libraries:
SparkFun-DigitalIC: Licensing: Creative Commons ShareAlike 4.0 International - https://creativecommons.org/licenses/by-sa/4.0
